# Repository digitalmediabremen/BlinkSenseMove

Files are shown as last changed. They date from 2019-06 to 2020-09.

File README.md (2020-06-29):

# Blink Sense Move.

A general purpose PCB/Toolkit for easy usage of sensors and actuators

# Hardware

1. maximum PCB dimensions: 100×100mm ( = 1,76/10pcs @[jlcpcb](http://jlcpcb.com) )
2. uses teensy 3.2 as mcu
3. features
  - 2 mosfets
  - h-bridge
  - amplfiers for external sensors
  - display (only dotmatrix for now, v2 will also offer pins for oled)
  - stepperdriver
  - clean audio output with lpf
  - potentiometers
  - buttons
  - patchable io
  
4. version 2 will feature
  - midi
  - choice of display
  - possibly cleaner powersolution

-----
## Pre v01

## MCU-Ideas

( supported by Arduino IDE )

1. ATmega328p (AVR, 20 MHz, 8-bit, @as_used_in(Arduino UNO)), pP 1.60€, [Datasheet](http://www.microchip.com/mymicrochip/filehandler.aspx?ddocname=en589666)
2. NXP MK20DX256 (ARM Cortex-M4, 96 MHz, 32-bit, @as_used_in(Teensy 3.2) ), pP 9.00€, [Datasheet](https://www.pjrc.com/teensy/K20P64M72SF1.pdf)
3. STM32F446RE (ARM Cortex-M4, 180 MHz, 32-bit, @as_used_in(Nucleo F446RE + Arduino for STM32)), pP 9.00€, [Datasheet](http://www.st.com/content/ccc/resource/technical/document/datasheet/65/cb/75/50/53/d6/48/24/DM00141306.pdf/files/DM00141306.pdf/jcr:content/translations/en.DM0014130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)

### Boards

1) Teensy LC (approx 13 Euro) | Teensy 3.2 (Pro: Fast, Audiocapabilitys. Contra: Not super cheap)
2) Arduino Nano (Pro: Compatibilty, cheap. Contra: CH340-Driver issue with cheap Variations)

## Ideas for Features

1) Felix´ Audio Output board
2) 1 or 2 Mosfets with Diodes
3) 12v Input with good Quality Voltage converter
4) Stepper Motor Driver
5) H-Bridge
6) 7-Segment-Display
7) Add-On-Interface for stuff like Encoders or Analogsticks and similiar stuff.
8) motor board *only* ( H-bridge+mosfet, stepper-driver, PWM for high-current/loads )
9) Making the wiring Modular
10) Mic- and Piezoamp, maybe also a switchable direct out to Felix Audio out.
11) frequency devider / counter ic
12) Making it modular (plugging and using boards together, with one microcontroller)
13) encoder
14) 2 potis

## Bill of materials
- 3.5 mm jack
- AKL
- 595 (SMD?)
- IRF530 (SMD)
- 7seg/4Digit
- spannungsregler MC7805CD2TG (SMD) (1A 5V für teensy und externe komponenten)

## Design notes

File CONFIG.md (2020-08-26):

# BSM Configuration

## Teensy
## Jumpers

Jumpers on BSM are used to create or break connections on the board. This allows to customize it to your needs.

Three kinds of Jumpers are used on the board
1. Black jumpers
    Black jumpers are freely configuable. They just break or create connections, mainly around the teensy. 
2. Red jumpers
    Red jumpers are danger jumpers! Take care when using these! These are used for configuring the powersupply and selecting between external power or usb power. It is possible to damage something with these, so think before jumping!
3. Blue jumpers
    blue jumpers are selection jumpers. They are used in certain places to select configuration, for example to configure the stepper driver or h-bridge.

## Power

## Stepper druver

## H-bridge

## Display

## Mosfet

## Betteraudioout

## Sensorport

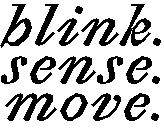
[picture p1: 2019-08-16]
hardware/pcb/DM_PCB_GRAPHICS/DM_PCB_EASTEREGG.BMP

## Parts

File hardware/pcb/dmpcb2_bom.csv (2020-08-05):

Part | Value | Device | Package | Description
3.3V |  | MA03-2 | MA03-2 | PIN HEADER
5V |  | MA03-2 | MA03-2 | PIN HEADER
14/DAC |  | JP1E | JP1 | JUMPER
C1 | 0.33uF | CPOL-EUSANYO_A' | SANYO-OSCON_A' | POLARIZED CAPACITOR, European symbol
C2 | 0.1uF | CPOL-EUSANYO_A' | SANYO-OSCON_A' | POLARIZED CAPACITOR, European symbol
C3 | 1000uf | CPOL-EUE3.5-8 | E3,5-8 | POLARIZED CAPACITOR, European symbol
C4 | 100nf | C-EUC0805 | C0805 | CAPACITOR, European symbol
C5 | 100nf | C-EUC0805 | C0805 | CAPACITOR, European symbol
C6 | 100nf | C-EUC0805 | C0805 | CAPACITOR, European symbol
C7 | 100uf | CPOL-EUE5-5 | E5-5 | POLARIZED CAPACITOR, European symbol
C8 | 100uf | CPOL-EUE5-5 | E5-5 | POLARIZED CAPACITOR, European symbol
C9 | 100uf | CPOL-EUE5-5 | E5-5 | POLARIZED CAPACITOR, European symbol
C10 | 100nf | C-EUC0805 | C0805 | CAPACITOR, European symbol
C11 | 10uf | C-EUC0805 | C0805 | CAPACITOR, European symbol
D3 | 1N4148DO35-7 | 1N4148DO35-7 | DO35-7 | DIODE
D4 | 1N4148DO35-7 | 1N4148DO35-7 | DO35-7 | DIODE
DRV8825 | POLOLU-DRV8825 | POLOLU-DRV8825 | POLOLU-DRV8825
EXT_5V |  | JP1E | JP1 | JUMPER
EXT_5V1 |  | JP1E | JP1 | JUMPER
GND |  | MA03-2 | MA03-2 | PIN HEADER
HOLA |  | JP1E | JP1 | JUMPER
HOLB |  | JP1E | JP1 | JUMPER
HOLC |  | JP1E | JP1 | JUMPER
HOLD |  | JP1E | JP1 | JUMPER
IC1 | 7805DT | 7805DT | TO252 | Positive VOLTAGE REGULATOR
IC2 | L293D | L293D | DIL16 | PUSH-PULL 4 CHANNEL DRIVER
IC4 | LM358D | LM358D | SO08 | OP AMP also LM158; LM258; LM2904
IC5 | LM358D | LM358D | SO08 | OP AMP also LM158; LM258; LM2904
J1 |  | CONN_11 | 1X11 | Multi connection point. Often used as Generic Header-pin footprint for 0.1 inch spaced/style header connections
J2 |  | CONN_14 | 1X14 | Multi connection point. Often used as Generic Header-pin footprint for 0.1 inch spaced/style header connections
J4 |  | CONN_03LOCK_LONGPADS | 1X03_LOCK_LONGPADS | Multi connection point. Often used as Generic Header-pin footprint for 0.1 inch spaced/style header connections
J7 | SJ-3523-SMT-TR | SJ-3523-SMT-TR | CUI_SJ-3523-SMT-TR | Audio Jack Connector 3.5 mm Low Profile Surface Mount Stereo Jack, 3 Pin Right-Angle
J8 |  | CONN_04 | 1X04 | Multi connection point. Often used as Generic Header-pin footprint for 0.1 inch spaced/style header connections
J9 |  | CONN_14 | 1X14 | Multi connection point. Often used as Generic Header-pin footprint for 0.1 inch spaced/style header connections
JP1 |  | JP2E | JP2 | JUMPER
JP3 |  | JP3Q | JP3Q | JUMPER
JP4 |  | JP2E | JP2 | JUMPER
JP5 |  | JP2E | JP2 | JUMPER
LED_01 |  | LEDSML0805 | SML0805 | LED
LED_02 |  | LEDSML0805 | SML0805 | LED
LED_03 |  | LEDSML0805 | SML0805 | LED
Q1 | IRF530 | IRF530 | TO220BV | HEXFET Power MOSFET
Q2 | IRF530 | IRF530 | TO220BV | HEXFET Power MOSFET
R1 | 100k | R-US_R0805 | R0805 | RESISTOR, American symbol
R2 | 1k | R-US_R0805 | R0805 | RESISTOR, American symbol
R3 | 100k | R-EU_R0805 | R0805 | RESISTOR, European symbol
R4 | 220R | R-EU_R0805 | R0805 | RESISTOR, European symbol
R5 | 100k | R-US_R0805 | R0805 | RESISTOR, American symbol
R6 | 1k | R-US_R0805 | R0805 | RESISTOR, American symbol
R7 | b10k | POTENTIOMETER_PT-10 | PT-10 | Potentiometer
R8 | b10k | POTENTIOMETER_PT-10 | PT-10 | Potentiometer
R9 | 1M | R-EU_M0805 | M0805 | RESISTOR, European symbol
R10 | 10M | R-EU_M0805 | M0805 | RESISTOR, European symbol
R11 | 10K | R-EU_M0805 | M0805 | RESISTOR, European symbol
R12 | 10k | R-EU_M0805 | M0805 | RESISTOR, European symbol
R13 | 10k | R-EU_M0805 | M0805 | RESISTOR, European symbol
R14 | 220R | R-EU_R0805 | R0805 | RESISTOR, European symbol
R15 | b100k | TRIM_EU-RJ9W | RJ9W | POTENTIOMETER
R16 | 10K | R-EU_M0805 | M0805 | RESISTOR, European symbol
R17 | b10k | TRIM_EU-RJ9W | RJ9W | POTENTIOMETER
R18 | 270R | R-EU_M0805 | M0805 | RESISTOR, European symbol
R19 | b10k | TRIM_EU-RJ9W | RJ9W | POTENTIOMETER
R20 | 220R | R-EU_R0805 | R0805 | RESISTOR, European symbol
S1 |  | 10-XX | B3F-10XX | OMRON SWITCH
S2 |  | 10-XX | B3F-10XX | OMRON SWITCH
SOCKET_IN |  | MA05-1 | MA05-1 | PIN HEADER
SOCKET_IN1 |  | MA05-1 | MA05-1 | PIN HEADER
STP_CONF |  | JP2E | JP2 | JUMPER
SV1 |  | MA07-1 | MA07-1 | PIN HEADER
SV2 |  | CONN_12 | 1X12 | Multi connection point. Often used as Generic Header-pin footprint for 0.1 inch spaced/style header connections
TEENSY3.2 | TEENSY_3.1-3.2_ALL_PINS&PADS | TEENSY_3.1-3.2_ALL_PINS&PADS | TEENSY_3.0-3.2_ALL_PINS_&_PADS | Footprint for Teensy 3.1 or 3.2 board using all pads and all through-holes. Pads need a 2x7 0.1 SMD header."
X1 |  | W237-102 | W237-102 | WAGO SCREW CLAMP
X2 |  | W237-4 | W237-4 | WAGO SCREW CLAMP
X3 |  | W237-102 | W237-102 | WAGO SCREW CLAMP
X4 |  | W237-102 | W237-102 | WAGO SCREW CLAMP
X5 |  | W237-102 | W237-102 | WAGO SCREW CLAMP
X6 |  | W237-102 | W237-102 | WAGO SCREW CLAMP
X7 |  | W237-102 | W237-102 | WAGO SCREW CLAMP
X8 |  | W237-102 | W237-102 | WAGO SCREW CLAMP

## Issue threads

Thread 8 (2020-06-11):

Labeling for J8 is missing

TimoJohannes, 2020-06-11:
add labeling to enable easier patching of second opamp circuit.

TimoJohannes, 2020-08-07:
added for v02

Closed 2020-08-07.

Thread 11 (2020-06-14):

Overthink display

TimoJohannes, 2020-06-14:
Dotmatrices are cool and all, but do they make sense didactically? maybe an oled display would make more sense? They are priced similarly as the dmds and offer greater and more vivid outputs.
Only problem is the noise they introduce into the powercircuit, maybe some good filtering could be used. Thanks felix for the input
Thoughts?

TimoJohannes, 2020-06-25:
Add Pins for 4 pin oled beneath the dotmatrix. User can chose what kind of display they want to use

TimoJohannes, 2020-07-14:
Done, added pins for 7pin oled + some filtering

Closed 2020-07-14.

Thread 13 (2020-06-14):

Add LEDs

TimoJohannes, 2020-06-14:
Adding one or two user controllable leds on board would offer some output possibilities.

TimoJohannes, 2020-08-07:
Added for v02

Closed 2020-08-07.

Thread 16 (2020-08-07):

Replace Footprint of headers

TimoJohannes, 2020-08-07:
Replace footprints of headers with the staggered ones from sparkfun, makes soldering them easier.

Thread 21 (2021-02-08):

Opamp gets fed with 5v, should only be powered by 3.3v. might damage teensy!

TimoJohannes, 2021-02-08:

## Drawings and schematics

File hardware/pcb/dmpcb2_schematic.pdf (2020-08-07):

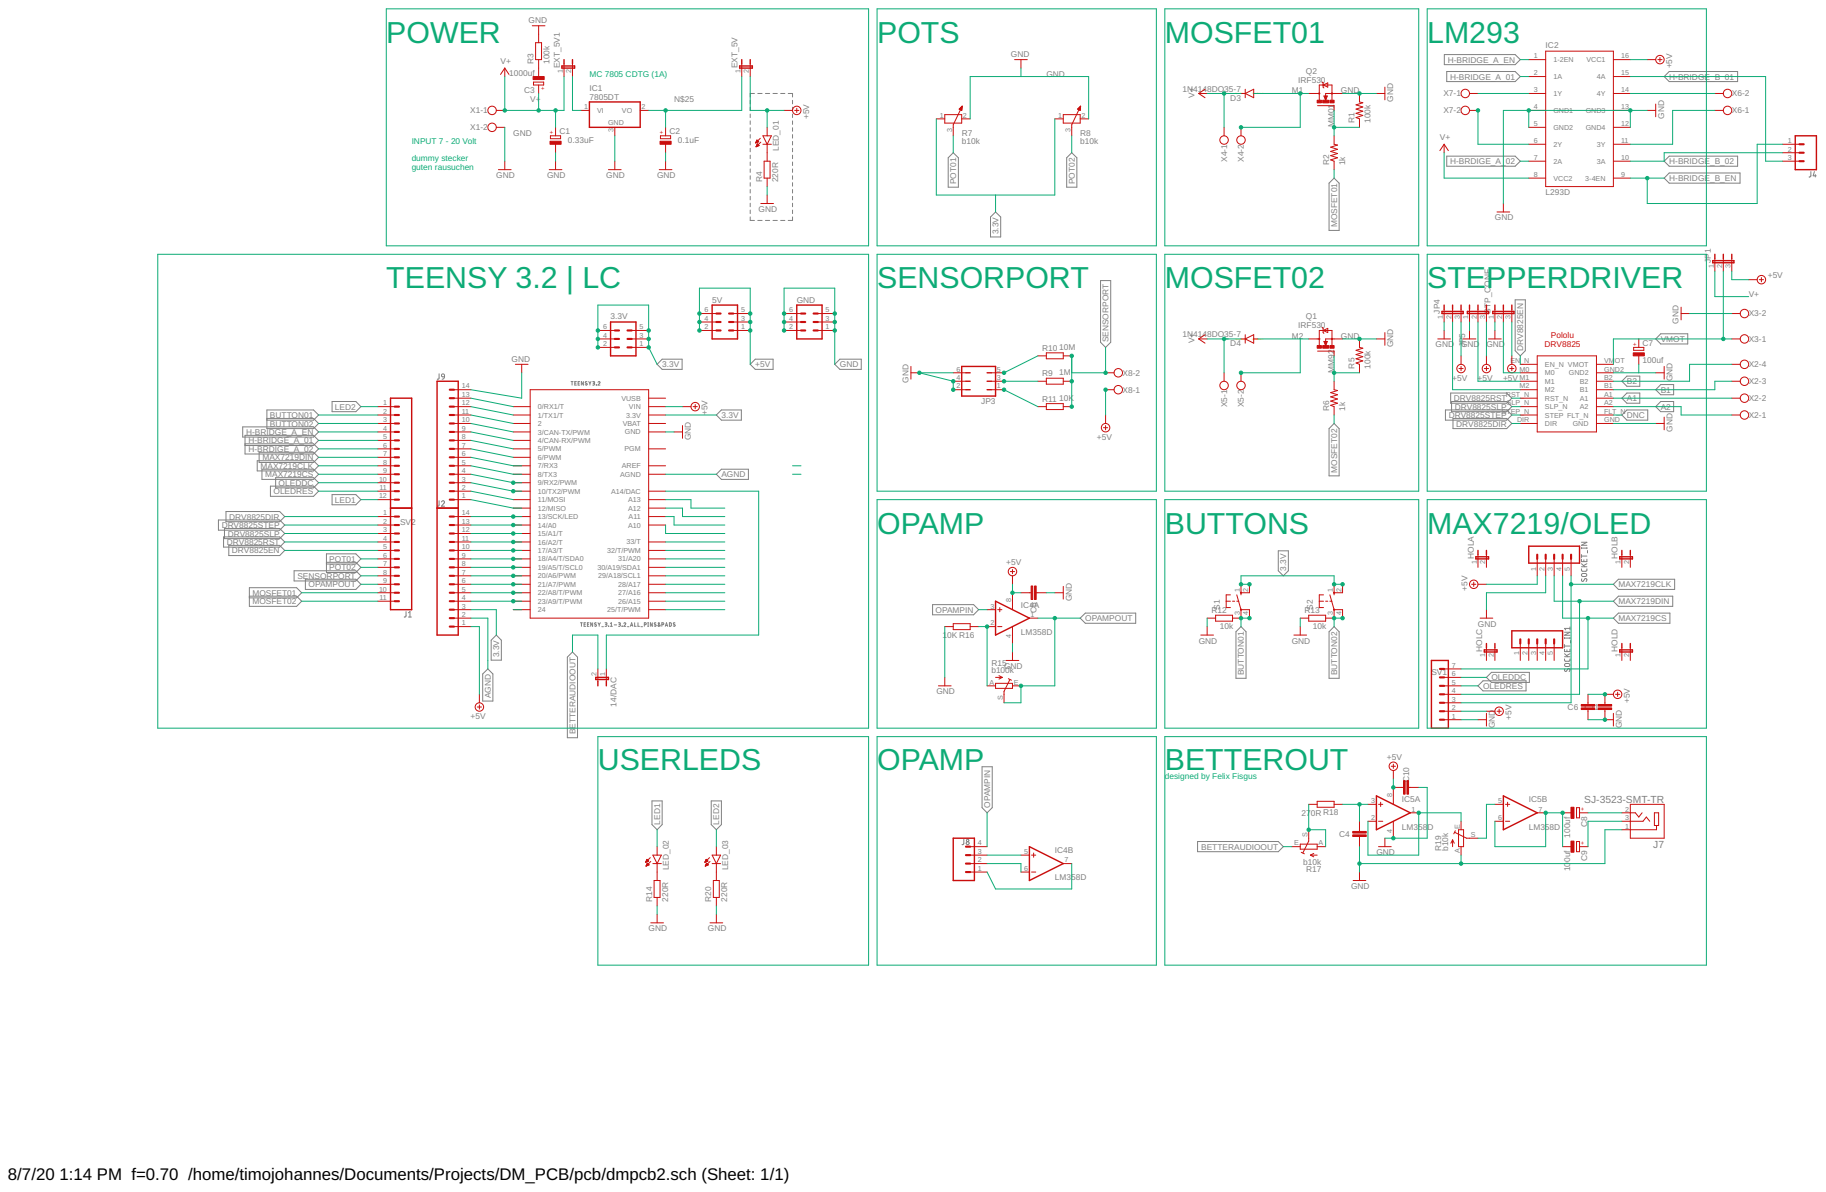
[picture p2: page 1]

6 OLEDDC

8/7/20 1:14 PM f=0.70 /home/timojohannes/Documents/Projects/DM_PCB/pcb/dmpcb2.sch (Sheet: 1/1)

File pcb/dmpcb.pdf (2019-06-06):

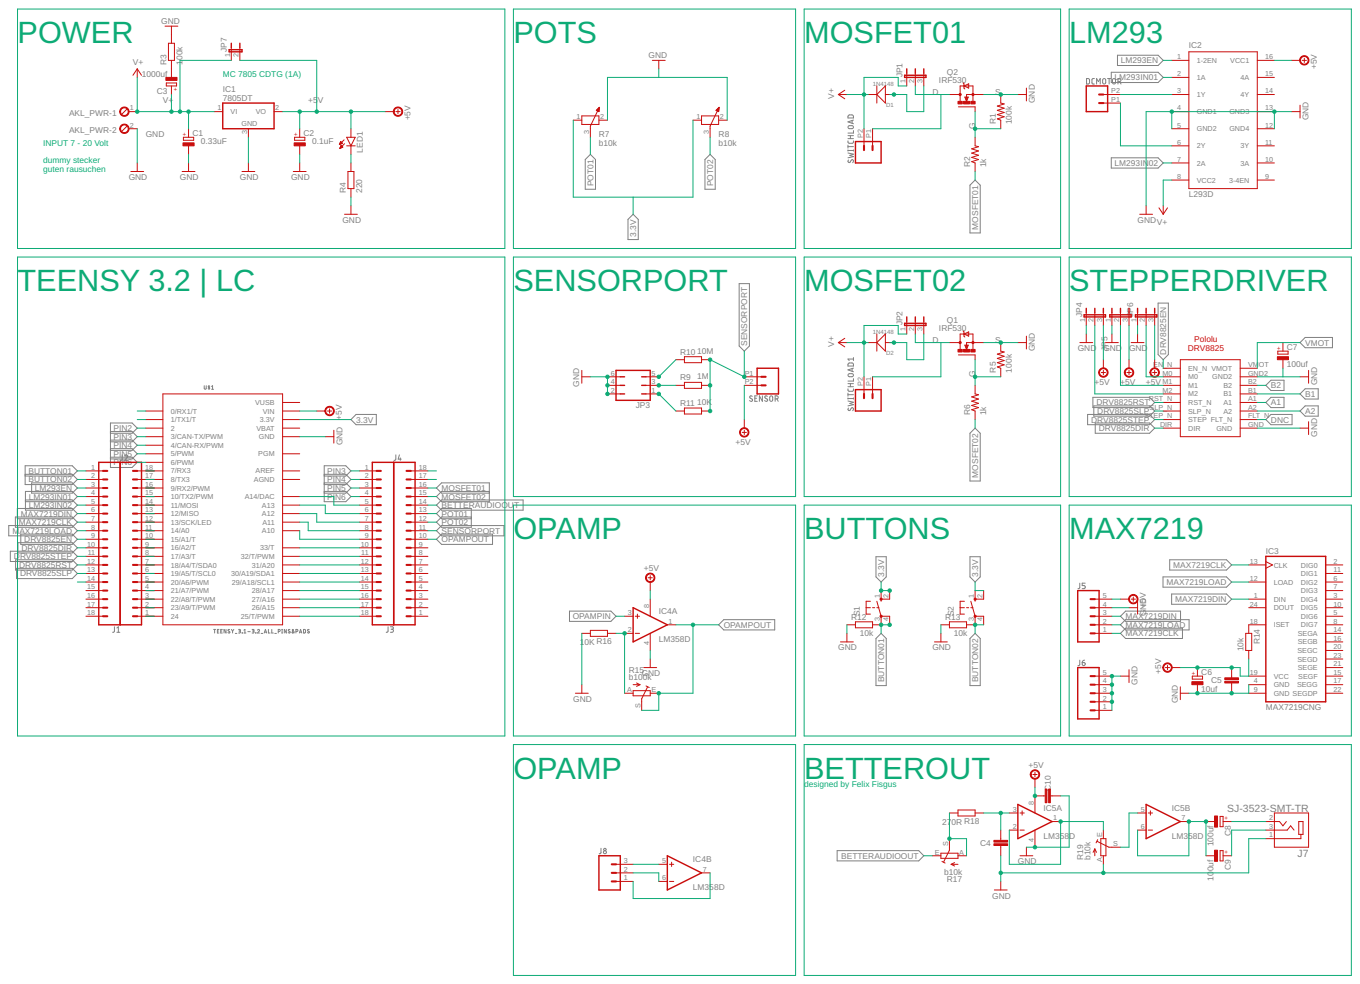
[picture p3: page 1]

12 | | 7
11 | | 8
10 | | 9
9 | 10
8 | 11

5 | 14
4 | 15
3 | 16

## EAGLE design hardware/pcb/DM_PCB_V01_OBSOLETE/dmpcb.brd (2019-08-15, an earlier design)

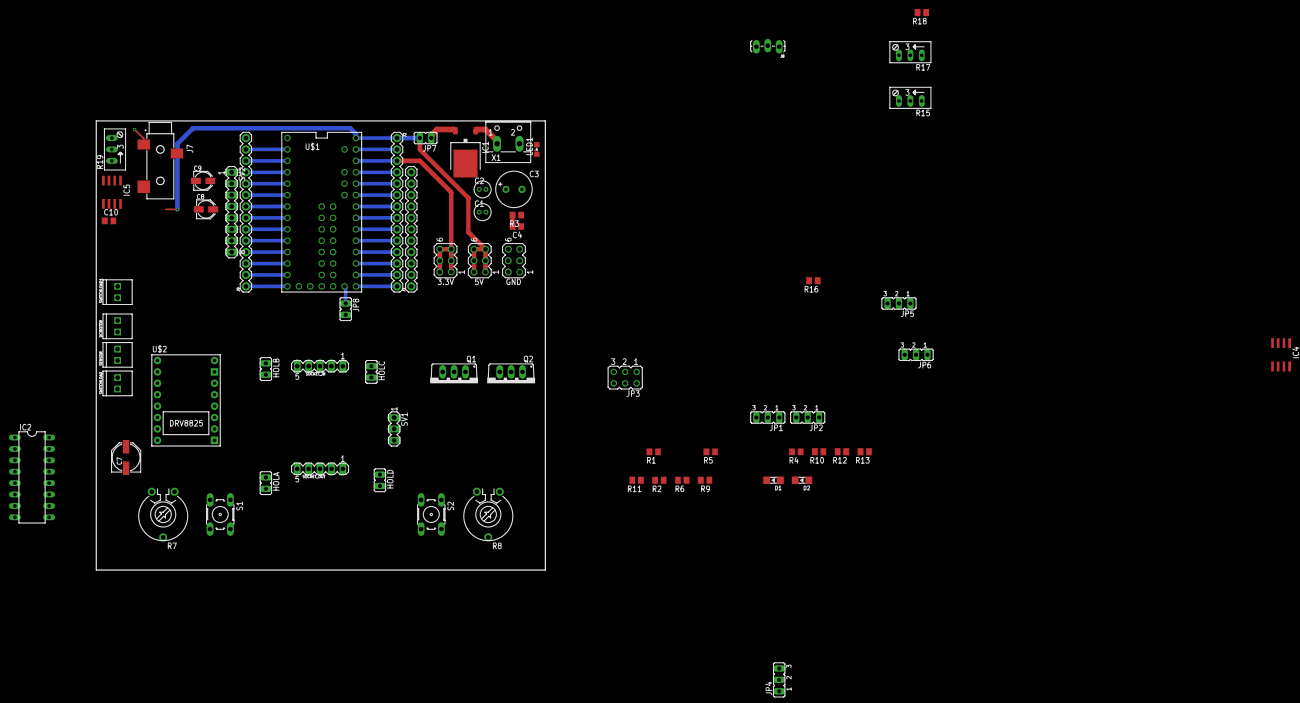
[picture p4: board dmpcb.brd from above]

Board: 2 copper layers, 100.0 x 100.0 mm, 68 parts (0 on the bottom side), 80 nets.

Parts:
3.3V, 5V: MA03-2
C1: 0.33uF; SANYO-OSCON_A'
C2: 0.1uF; SANYO-OSCON_A'
C3: 1000uf; E3,5-8
C4, C10: 100nf; C0805
C7: 100uf; PANASONIC_D
C8, C9: 100uf; PANASONIC_B
D1, D2: 1N4148; LL-34
DCMOTOR: 1X02_2.54_SCREWTERM
GND: MA03-2
HOLA: JP1
HOLB: JP1
HOLC: JP1
HOLD: JP1
IC1: 7805DT; TO252
IC2: L293D; DIL16
IC4, IC5: LM358D; SO08
J1: 1X11
J2, J9: 1X14
J7: SJ-3523-SMT-TR; CUI_SJ-3523-SMT-TR
J8: 1X03_LOCK_LONGPADS
JP1, JP2, JP4, JP5, JP6: JP2
JP3: JP3Q
JP7, JP8: JP1
LED1: SML0805
Q1, Q2: IRF530; TO220BV
R1, R3, R5: 100k; R0805
R2, R6: 1k; R0805
R4: 220; R0805
R7, R8: b10k; PT-10
R9: 1M; M0805
R10: 10M; M0805
R11, R16: 10K; M0805
R12, R13: 10k; M0805
R15: b100k; RJ9W
R17, R19: b10k; RJ9W
R18: 270R; M0805
S1, S2: B3F-10XX
SENSOR: 1X02_2.54_SCREWTERM
SOCKET_IN: MA05-1
SOCKET_OUT: MA05-1
SV1: MA03-1
SV2: MA08-1
SWITCHLOAD, SWITCHLOAD1: 1X02_2.54_SCREWTERM
U$1: TEENSY_3.1-3.2_ALL_PINS&PADS; TEENSY_3.0-3.2_ALL_PINS_&_PADS
U$2: POLOLU-DRV8825
X1: W237-102

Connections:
3.3V: 3.3V.1, 3.3V.2, 3.3V.3, 3.3V.4, 3.3V.5, 3.3V.6, J2.3, R7.1, R8.1, U$1.3.3V, U$1.3.3V1, U$1.3.3V2
+5V: 5V.1, 5V.2, 5V.3, 5V.4, 5V.5, 5V.6, C10.2, IC2.16, IC4.8, IC5.8, J2.1, JP4.3, JP5.3, JP6.3, JP7.2, SENSOR.P2, SOCKET_IN.1, U$1.VIN
AGND: J2.2, U$1.AGND
BETTERAUDIOOUT: JP8.2, R17.E
BUTTON01: R12.2, S1.3, S1.4, SV2.1
BUTTON02: R13.2, S2.3, S2.4, SV2.2
D: JP1.2, JP2.2, Q1.D, Q2.D, SWITCHLOAD.P1, SWITCHLOAD1.P1
DRV8825DIR: J1.2, U$2.DIR
DRV8825EN: J1.1, U$2.EN_N
DRV8825RST: J1.4, U$2.RST_N
DRV8825SLP: J1.5, U$2.SLP_N
DRV8825STEP: J1.3, U$2.STEP_N
G: Q1.G, Q2.G, R1.1, R2.2, R5.1, R6.2
GND: C1.-, C2.-, C4.2, C7.-, C10.1, GND.1, GND.2, GND.3, GND.4, GND.5, GND.6, IC1.3, IC2.4, IC2.5, IC2.12, IC2.13, IC4.4, IC5.4, J7.1, J9.14, JP3.2, JP3.4, JP3.6, JP4.1, JP5.1, JP6.1, R3.2, R4.1, R7.2, R8.2, R12.1, R13.1, R16.2, R19.A, SOCKET_IN.2, U$1.GND, U$1.GND1, U$1.GND2, U$2.GND, U$2.GND2, X1.2
LM293EN: IC2.1, SV2.3
LM293IN01: IC2.2, SV2.4
LM293IN02: IC2.7, SV2.5
MAX7219CLK: SOCKET_IN.5, SV1.1, SV2.7
MAX7219CS: SOCKET_IN.4, SV1.2, SV2.8
MAX7219DIN: SOCKET_IN.3, SV1.3, SV2.6
MOSFET01: J1.10, R2.1
MOSFET02: J1.11, R6.1
unnamed: DCMOTOR.P2, IC2.3
unnamed: DCMOTOR.P1, IC2.6
unnamed: C3.-, R3.1
unnamed: LED1.C, R4.2
unnamed: D2.A, JP2.3
unnamed: D1.A, JP1.3
unnamed: JP3.5, R10.1
unnamed: JP3.3, R9.1
unnamed: JP3.1, R11.1
unnamed: S1.1, S1.2
unnamed: IC4.5, J8.3
unnamed: S2.1, S2.2
unnamed: J2.4, U$1.23/A9
unnamed: C2.+, IC1.2, JP7.1, LED1.A
unnamed: J2.5, U$1.22/A8
unnamed: J2.6, U$1.21/A7
unnamed: J2.7, U$1.20/A6
unnamed: J2.8, U$1.19/A5
unnamed: J2.9, U$1.18/A4
unnamed: J2.10, U$1.17/A3
unnamed: J2.11, U$1.16/A2
unnamed: J2.12, U$1.15/A1
unnamed: J2.13, U$1.14/A0
unnamed: J2.14, U$1.13
unnamed: J9.1, U$1.12
unnamed: J9.2, U$1.11
unnamed: J9.3, U$1.10
unnamed: J9.4, U$1.9
unnamed: J9.5, U$1.8
unnamed: J9.6, U$1.7
unnamed: JP8.1, U$1.RESET/DAC
unnamed: JP4.2, U$2.M2
unnamed: JP5.2, U$2.M1
unnamed: JP6.2, U$2.M0
unnamed: J9.12, U$1.1
unnamed: J9.13, U$1.0
unnamed: IC4.2, R15.A, R16.1
unnamed: C8.+, J7.2
unnamed: R17.A, R17.S, R18.2
unnamed: C4.1, IC5.3, R18.1
unnamed: IC5.1, IC5.2, R19.E
unnamed: IC4.6, J8.2
unnamed: IC5.5, R19.S
unnamed: C8.-, C9.-, IC5.6, IC5.7
unnamed: C9.+, J7.3
unnamed: IC4.7, J8.1
OPAMPOUT: IC4.1, J1.9, R15.E, R15.S
PIN2: J9.11, U$1.2
PIN3: J9.10, U$1.3
PIN4: J9.9, U$1.4
PIN5: J9.8, U$1.5
PIN6: J9.7, U$1.6
POT01: J1.6, R7.3
POT02: J1.7, R8.3
S: Q1.S, Q2.S, R1.2, R5.2
SENSORPORT: J1.8, R9.2, R10.2, R11.2, SENSOR.P1
V+: C1.+, C3.+, D1.C, D2.C, IC1.1, IC2.8, JP1.1, JP2.1, SWITCHLOAD.P2, SWITCHLOAD1.P2, X1.1
VMOT: C7.+, U$2.VMOT

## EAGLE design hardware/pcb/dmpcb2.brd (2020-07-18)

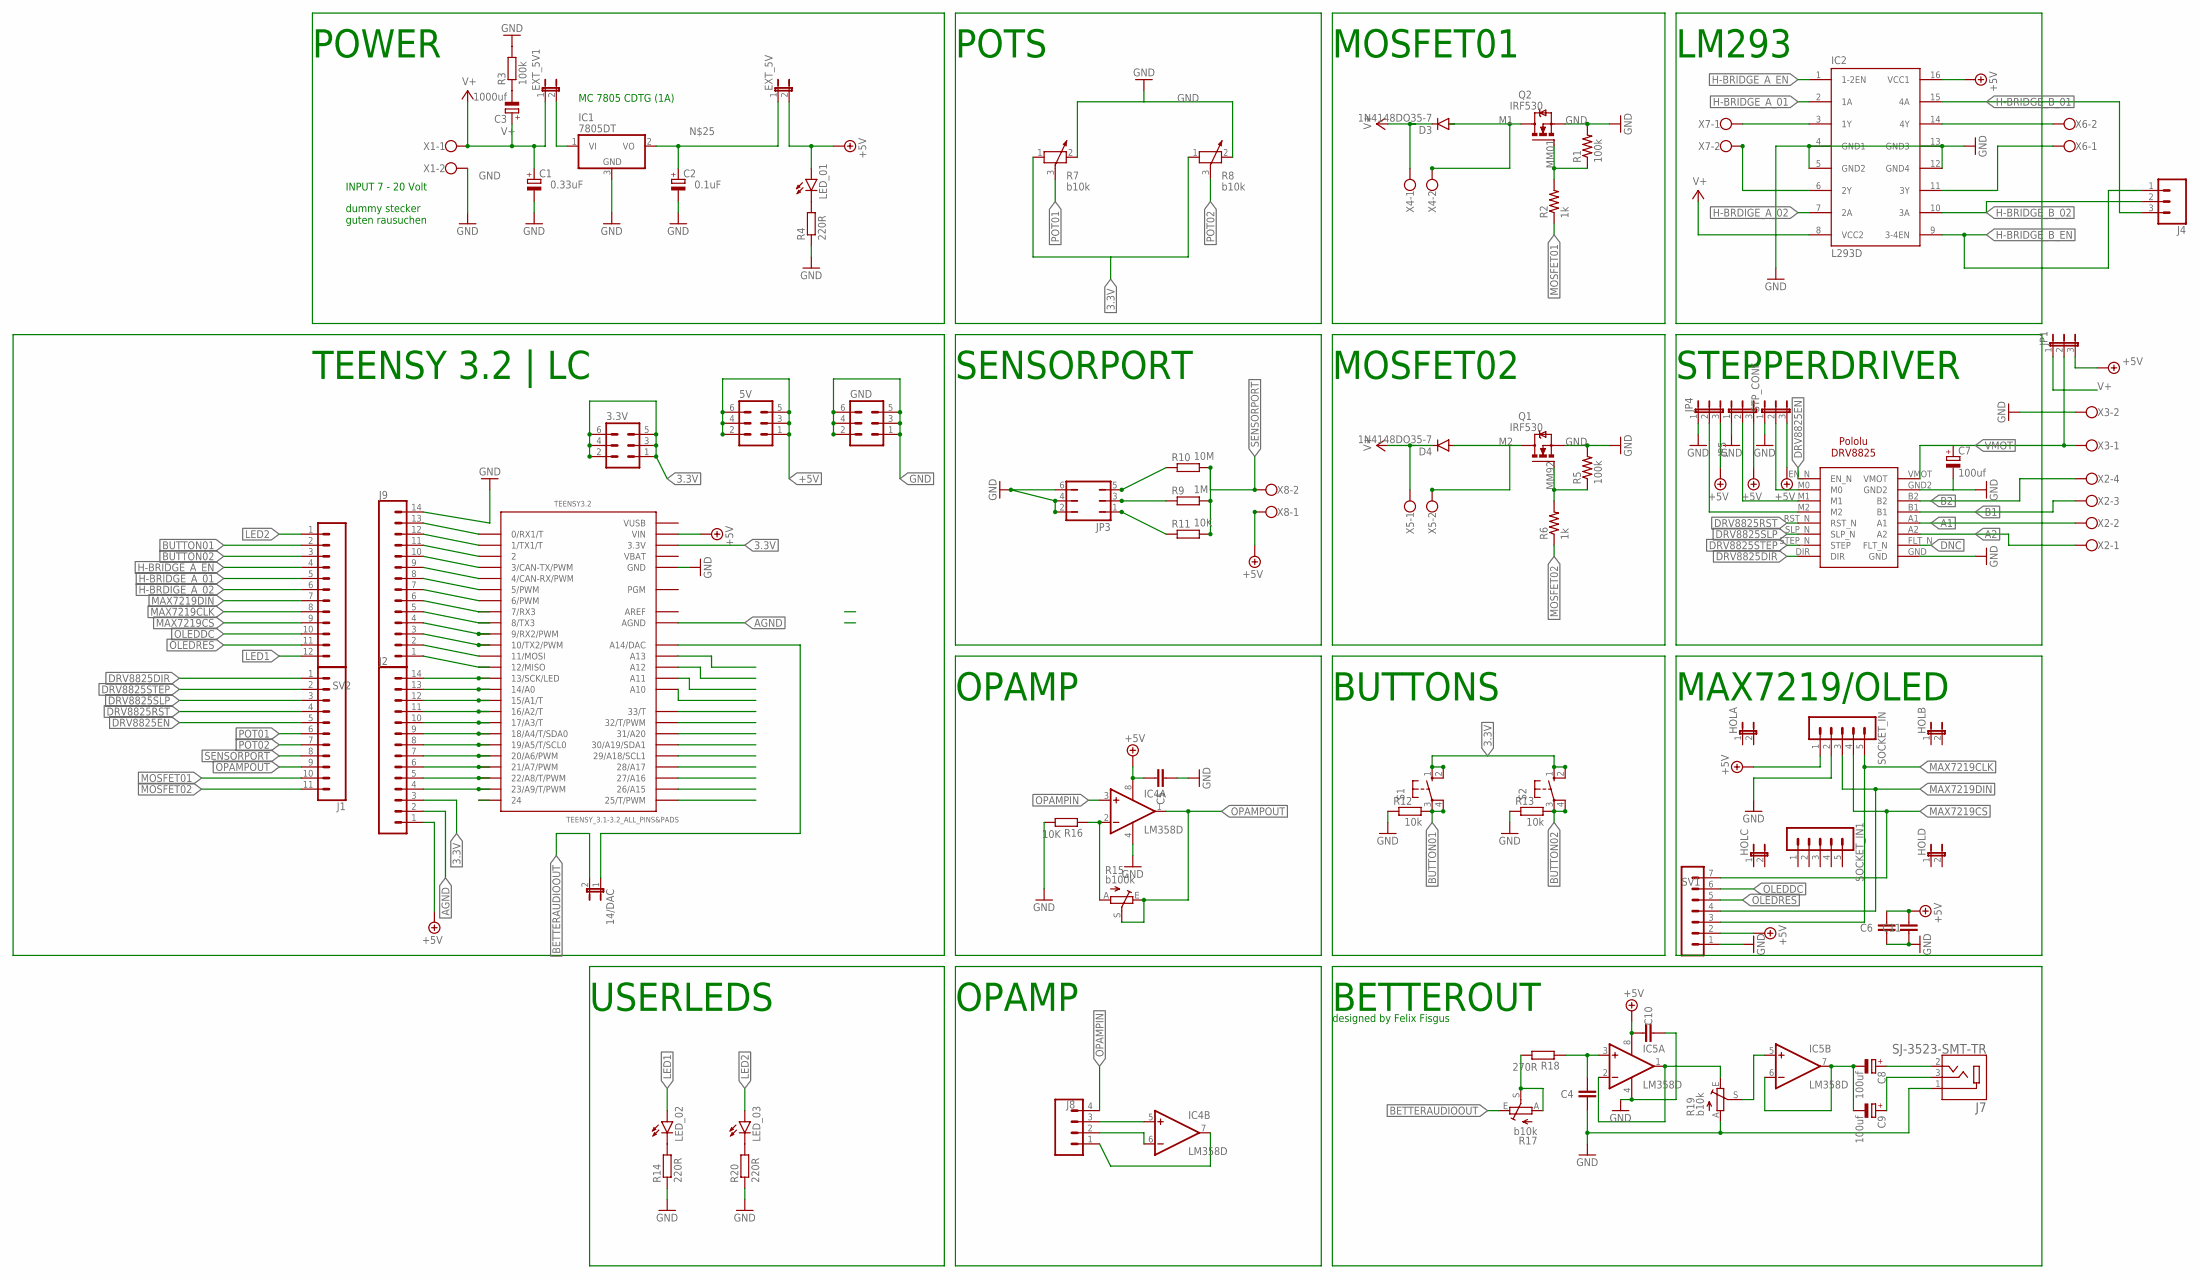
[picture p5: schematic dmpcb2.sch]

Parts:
3.3V, 5V: MA03-2
14/DAC: JP1E; JP1
C1: 0.33uF; SANYO-OSCON_A'
C2: 0.1uF; SANYO-OSCON_A'
C3: 1000uf; E3,5-8
C4, C5, C6, C10: 100nf; C0805
C7, C8, C9: 100uf; E5-5
C11: 10uf; C0805
D3, D4: 1N4148DO35-7; DO35-7
DRV8825: POLOLU-DRV8825
EXT_5V, EXT_5V1: JP1E; JP1
GND: MA03-2
HOLA: JP1E; JP1
HOLB: JP1E; JP1
HOLC: JP1E; JP1
HOLD: JP1E; JP1
IC1: 7805DT; TO252
IC2: L293D; DIL16
IC4, IC5: LM358D; SO08
J1: CONN_11; 1X11
J2, J9: CONN_14; 1X14
J4: CONN_03LOCK_LONGPADS; 1X03_LOCK_LONGPADS
J7: SJ-3523-SMT-TR; CUI_SJ-3523-SMT-TR
J8: CONN_04; 1X04
JP1, JP4, JP5: JP2E; JP2
JP3: JP3Q
LED_01, LED_02, LED_03: LEDSML0805; SML0805
Q1, Q2: IRF530; TO220BV
R1, R3, R5: 100k; R0805
R2, R6: 1k; R0805
R4, R14, R20: 220R; R0805
R7, R8: b10k; PT-10
R9: 1M; M0805
R10: 10M; M0805
R11, R16: 10K; M0805
R12, R13: 10k; M0805
R15: b100k; RJ9W
R17, R19: b10k; RJ9W
R18: 270R; M0805
S1, S2: 10-XX; B3F-10XX
SOCKET_IN, SOCKET_IN1: MA05-1
STP_CONF: JP2E; JP2
SV1: MA07-1
SV2: CONN_12; 1X12
TEENSY3.2: TEENSY_3.1-3.2_ALL_PINS&PADS; TEENSY_3.0-3.2_ALL_PINS_&_PADS
X1, X3, X4, X5, X6, X7, X8: W237-102
X2: W237-4

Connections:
3.3V: 3.3V.1, 3.3V.2, 3.3V.3, 3.3V.4, 3.3V.5, 3.3V.6, J2.3, R7.1, R8.1, S1.1 (S), S1.2 (S1), S2.1 (S), S2.2 (S1), TEENSY3.2.3.3V, TEENSY3.2.3.3V1 (3.3V), TEENSY3.2.3.3V2 (3.3V)
+5V: 5V.1, 5V.2, 5V.3, 5V.4, 5V.5, 5V.6, C5.1, C6.1, C10.2, C11.1, EXT_5V.2, IC2.16 (VCC1), IC4.8 (V+), IC5.8 (V+), J2.1, JP1.3, JP4.3, JP5.3, LED_01.A, SOCKET_IN.1, STP_CONF.3, SV1.2, TEENSY3.2.VIN, X8.1
A1: DRV8825.A1, X2.2
A2: DRV8825.A2, X2.1
AGND: J2.2, TEENSY3.2.AGND
AREF: TEENSY3.2.AREF
B1: DRV8825.B1, X2.3
B2: DRV8825.B2, X2.4
BETTERAUDIOOUT: 14/DAC.2, R17.E
BUTTON01: R12.2, S1.3, S1.4 (P1), SV2.2
BUTTON02: R13.2, S2.3, S2.4 (P1), SV2.3
DNC: DRV8825.FLT_N
DRV8825DIR: DRV8825.DIR, J1.1
DRV8825EN: DRV8825.EN_N, J1.5
DRV8825RST: DRV8825.RST_N, J1.4
DRV8825SLP: DRV8825.SLP_N, J1.3
DRV8825STEP: DRV8825.STEP_N (STEP), J1.2
GND: C1.-, C2.-, C4.2, C5.2, C6.2, C7.-, C10.1, C11.2, DRV8825.GND, DRV8825.GND2, GND.1, GND.2, GND.3, GND.4, GND.5, GND.6, IC1.3 (GND), IC2.4 (GND1), IC2.5 (GND2), IC2.12 (GND4), IC2.13 (GND3), IC4.4 (V-), IC5.4 (V-), J7.1, J9.14, JP3.2, JP3.4, JP3.6, JP4.1, JP5.1, Q1.S, Q2.S, R1.2, R3.2, R4.1, R5.2, R7.2, R8.2, R12.1, R13.1, R14.1, R16.2, R19.A, R20.1, SOCKET_IN.2, STP_CONF.1, SV1.1, TEENSY3.2.GND, TEENSY3.2.GND1 (GND), TEENSY3.2.GND2 (GND), X1.2, X3.2
H-BRDIGE_A_02: IC2.7 (2A), SV2.6
H-BRIDGE_A_01: IC2.2 (1A), SV2.5
H-BRIDGE_A_EN: IC2.1 (1-2EN), SV2.4
H-BRIDGE_B_01: IC2.15 (4A), J4.3
H-BRIDGE_B_02: IC2.10 (3A), J4.2
H-BRIDGE_B_EN: IC2.9 (3-4EN), J4.1
LED1: LED_02.A, SV2.12
LED2: LED_03.A, SV2.1
M1: D3.A, Q2.D, X4.2
M2: D4.A, Q1.D, X5.2
MAX7219CLK: SOCKET_IN.5, SV1.3, SV2.8
MAX7219CS: SOCKET_IN.4, SV1.7, SV2.9
MAX7219DIN: SOCKET_IN.3, SV1.4, SV2.7
MM01: Q2.G, R1.1, R2.2
MM92: Q1.G, R5.1, R6.2
MOSFET01: J1.10, R2.1
MOSFET02: J1.11, R6.1
unnamed: IC2.3 (1Y), X7.1
unnamed: IC2.6 (2Y), X7.2
unnamed: C3.-, R3.1
unnamed: LED_01.C, R4.2
unnamed: IC2.14 (4Y), X6.2
unnamed: IC2.11 (3Y), X6.1
unnamed: JP3.5, R10.1
unnamed: JP3.3, R9.1
unnamed: JP3.1, R11.1
unnamed: EXT_5V1.2, IC1.1 (VI)
unnamed: IC4.5 (+IN), J8.3
unnamed: J2.4, TEENSY3.2.23/A9 (23/A9/T/PWM)
unnamed: C2.+, EXT_5V.1, IC1.2 (VO)
unnamed: J2.5, TEENSY3.2.22/A8 (22/A8/T/PWM)
unnamed: J2.6, TEENSY3.2.21/A7 (21/A7/PWM)
unnamed: J2.7, TEENSY3.2.20/A6 (20/A6/PWM)
unnamed: J2.8, TEENSY3.2.19/A5 (19/A5/T/SCL0)
unnamed: J2.9, TEENSY3.2.18/A4 (18/A4/T/SDA0)
unnamed: J2.10, TEENSY3.2.17/A3 (17/A3/T)
unnamed: J2.11, TEENSY3.2.16/A2 (16/A2/T)
unnamed: J2.12, TEENSY3.2.15/A1 (15/A1/T)
unnamed: J2.13, TEENSY3.2.14/A0
unnamed: J2.14, TEENSY3.2.13 (13/SCK/LED)
unnamed: J9.1, TEENSY3.2.12 (12/MISO)
unnamed: J9.2, TEENSY3.2.11 (11/MOSI)
unnamed: J9.3, TEENSY3.2.10 (10/TX2/PWM)
unnamed: J9.4, TEENSY3.2.9 (9/RX2/PWM)
unnamed: J9.5, TEENSY3.2.8 (8/TX3)
unnamed: J9.6, TEENSY3.2.7 (7/RX3)
unnamed: 14/DAC.1, TEENSY3.2.RESET/DAC (A14/DAC)
unnamed: DRV8825.M2, JP4.2
unnamed: DRV8825.M1, JP5.2
unnamed: DRV8825.M0, STP_CONF.2
unnamed: J9.12, TEENSY3.2.1 (1/TX1/T)
unnamed: J9.13, TEENSY3.2.0 (0/RX1/T)
unnamed: IC4.2 (-IN), R15.A, R16.1
unnamed: LED_02.C, R14.2
unnamed: C8.+, J7.2
unnamed: R17.A, R17.S, R18.2
unnamed: C4.1, IC5.3 (+IN), R18.1
unnamed: IC5.1 (OUT), IC5.2 (-IN), R19.E
unnamed: IC4.6 (-IN), J8.2
unnamed: IC5.5 (+IN), R19.S
unnamed: C8.-, C9.-, IC5.6 (-IN), IC5.7 (OUT)
unnamed: C9.+, J7.3
unnamed: IC4.7 (OUT), J8.1
unnamed: LED_03.C, R20.2
OLEDDC: SV1.6, SV2.10
OLEDRES: SV1.5, SV2.11
OPAMPIN: IC4.3 (+IN), J8.4
OPAMPOUT: IC4.1 (OUT), J1.9, R15.E, R15.S
PIN2: J9.11, TEENSY3.2.2
PIN3: J9.10, TEENSY3.2.3 (3/CAN-TX/PWM)
PIN4: J9.9, TEENSY3.2.4 (4/CAN-RX/PWM)
PIN5: J9.8, TEENSY3.2.5 (5/PWM)
PIN6: J9.7, TEENSY3.2.6 (6/PWM)
POT01: J1.6, R7.3
POT02: J1.7, R8.3
SENSORPORT: J1.8, R9.2, R10.2, R11.2, X8.2
V+: C1.+, C3.+, D3.C, D4.C, EXT_5V1.1, IC2.8 (VCC2), JP1.1, X1.1, X4.1, X5.1
VBAT: TEENSY3.2.VBAT
VMOT: C7.+, DRV8825.VMOT, JP1.2, X3.1
VUSB: TEENSY3.2.VUSB

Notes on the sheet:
POWER
INPUT 7 - 20 Volt
MC 7805 CDTG (1A)
TEENSY 3.2 | LC
dummy stecker guten rausuchen
MOSFET01
LM293
MOSFET02
POTS
STEPPERDRIVER
SENSORPORT
BUTTONS
MAX7219/OLED
OPAMP
BETTEROUT
designed by Felix Fisgus
USERLEDS

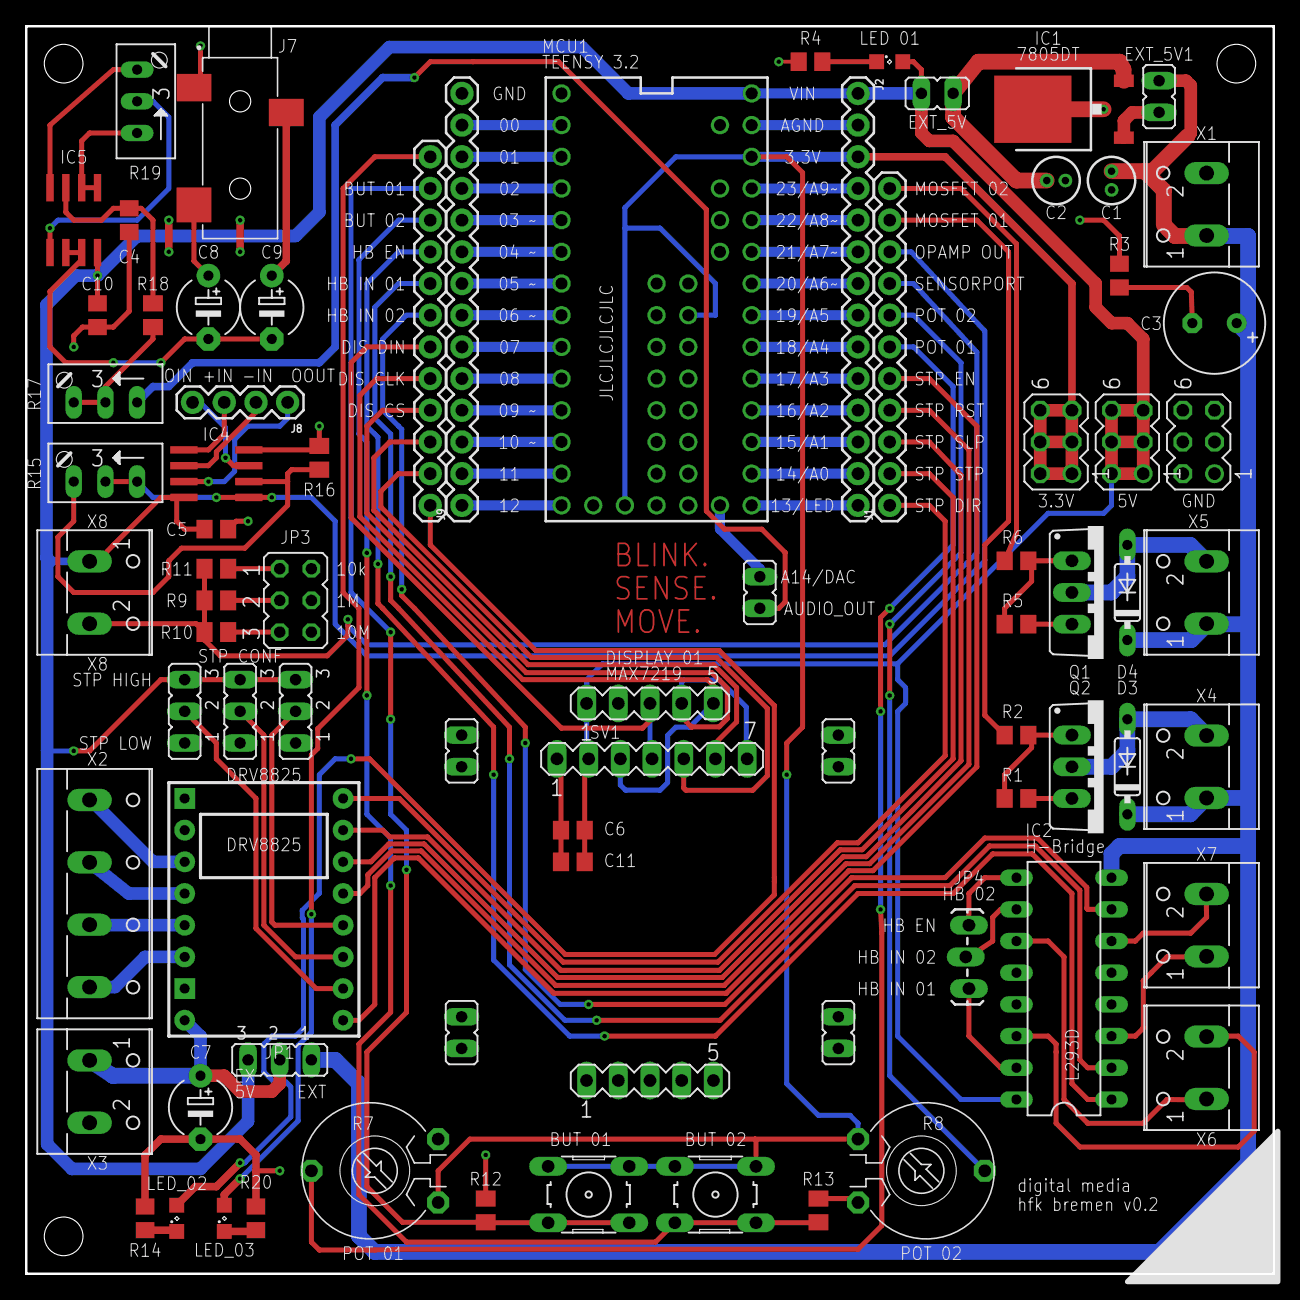
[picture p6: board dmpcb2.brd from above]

Board: 2 copper layers, 100.0 x 100.0 mm, 79 parts (0 on the bottom side), 94 nets.

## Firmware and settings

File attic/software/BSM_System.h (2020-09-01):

#pragma once

//Buttons
#define BUTTON_01 2
#define BUTTON_02 3

//H-Bridge, first half
#define HBRIDGE_ENABLE 4
#define HBRIDGE_IN_01 5
#define HBRIDGE_IN_02 6

//Display, Dotmatrix
#define DISPLAY_DIN 7
#define DISPLAY_CLK 8
#define DISPLAY_CS 9

//Display, OLED, Uncomment the following lines
/*
#define DISPLAY_DC 10
#define DISPLAY_RES 11
*/

//LEDs
#define LED_01 12
#define LED_02 1

//Stepper driver 
#define STEPPER_DIR 13 //Also switches on board LED of Teensy
#define STEPPER_STP 14
#define STEPPER_SLP 15
#define STEPPER_RST 16
#define STEPPER_EN 17

//Potentiometers
#define POTENTIOMETER_01 18
#define POTENTIOMETER_02 19

//Sensorport
#define SENSORPORT 20

//Opamp
#define OPAMP_OUT 21

//Mosfets
#define MOSFET_01 22
#define MOSFET_02 23

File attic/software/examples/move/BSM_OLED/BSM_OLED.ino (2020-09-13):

/**************************************************************************
 This sektch demonstrates the use of OLEDs based on SSD1306 drivers
 with the Blink Sense Move Board.
 To use the OLED connect the corresponding pins for the display (DISPLAY_CLK, DISPLAY_CS, DISPLAY_DC, DISPLAY_DIN and DISPLAY_RES) to their Teensy pins using jumpers.

 It is based on the on the Adafruit OLED example.

 This example is for a 128x64 pixel display using SPI to communicate
 4 or 5 pins are required to interface.

 Original sketch written by Limor Fried/Ladyada for Adafruit Industries,
 with contributions from the open source community.
 BSD license, check license.txt for more information
 All text above, and the splash screen below must be
 included in any redistribution.
 **************************************************************************/

/* include the libraries used in this sketch.*/
#include <SPI.h>
#include <Wire.h>
#include <Adafruit_GFX.h>
#include <Adafruit_SSD1306.h>
#include "BSM_System.h"

/* defines screen width and hight of the display in pixels*/
#define SCREEN_WIDTH 128
#define SCREEN_HEIGHT 64

/* initiates the display with the corresponding pins.*/
Adafruit_SSD1306 display(SCREEN_WIDTH, SCREEN_HEIGHT,
  DISPLAY_DIN, DISPLAY_CLK, DISPLAY_DC, DISPLAY_RES, DISPLAY_CS);


/* Comment out above, uncomment this block to use hardware SPI
#define OLED_DC     6
#define OLED_CS     7
#define OLED_RESET  8
Adafruit_SSD1306 display(SCREEN_WIDTH, SCREEN_HEIGHT,
  &SPI, OLED_DC, OLED_RESET, OLED_CS);
*/

/* Number of snowflakes in the animation example*/
#define NUMFLAKES     10 

#define LOGO_HEIGHT   16
#define LOGO_WIDTH    16
static const unsigned char PROGMEM logo_bmp[] = { B00000000, B11000000,
  B00000001, B11000000,
  B00000001, B11000000,
  B00000011, B11100000,
  B11110011, B11100000,
  B11111110, B11111000,
  B01111110, B11111111,
  B00110011, B10011111,
  B00011111, B11111100,
  B00001101, B01110000,
  B00011011, B10100000,
  B00111111, B11100000,
  B00111111, B11110000,
  B01111100, B11110000,
  B01110000, B01110000,
  B00000000, B00110000 };

void setup() {
  Serial.begin(9600);

  /* SSD1306_SWITCHCAPVCC = generate display voltage from 3.3V internally */
  if(!display.begin(SSD1306_SWITCHCAPVCC)) {
    Serial.println(F("SSD1306 allocation failed"));
    /*Don't proceed, loop forever */
    for(;;); 
  }

  /* Show initial display buffer contents on the screen --
  the library initializes this with an Adafruit splash screen.*/
  display.display();
  delay(2000);

  /* Clear the buffer */
  display.clearDisplay();

  /* Draw a single pixel in white */
  display.drawPixel(10, 10, SSD1306_WHITE);

  /* Show the display buffer on the screen. You MUST call display() after
  drawing commands to make them visible on screen! */
  display.display();
  delay(2000);
  /* display.display() is NOT necessary after every single drawing command,
  unless that's what you want...rather, you can batch up a bunch of
  drawing operations and then update the screen all at once by calling
  display.display(). These examples demonstrate both approaches... */

  testdrawline();      /* Draw many lines*/

  testdrawrect();      /* Draw rectangles (outlines)*/

  testfillrect();      /* Draw rectangles (filled)*/

  testdrawcircle();    /* Draw circles (outlines)*/

  testfillcircle();    /* Draw circles (filled)*/

  testdrawroundrect(); /* Draw rounded rectangles (outlines)*/

  testfillroundrect(); /* Draw rounded rectangles (filled)*/

  testdrawtriangle();  /* Draw triangles (outlines)*/

  testfilltriangle();  /* Draw triangles (filled)*/

  testdrawchar();      /* Draw characters of the default font*/

  testdrawstyles();    /* Draw 'stylized' characters*/

  testscrolltext();    /* Draw scrolling text*/

  testdrawbitmap();    /* Draw a small bitmap image*/

  /* Invert and restore display, pausing in-between*/
  display.invertDisplay(true);
  delay(1000);
  display.invertDisplay(false);
  delay(1000);

  /* Animate bitmaps*/
  testanimate(logo_bmp, LOGO_WIDTH, LOGO_HEIGHT); 
}

void loop() {
}

void testdrawline() {
  int16_t i;

  /* Clear display buffer*/
  display.clearDisplay(); 

  for(i=0; i<display.width(); i+=4) {
    display.drawLine(0, 0, i, display.height()-1, SSD1306_WHITE);
    display.display(); /* Update screen with each newly-drawn line*/
    delay(1);
  }
  for(i=0; i<display.height(); i+=4) {
    display.drawLine(0, 0, display.width()-1, i, SSD1306_WHITE);
    display.display();
    delay(1);
  }
  delay(250);

  display.clearDisplay();

  for(i=0; i<display.width(); i+=4) {
    display.drawLine(0, display.height()-1, i, 0, SSD1306_WHITE);
    display.display();
    delay(1);
  }
  for(i=display.height()-1; i>=0; i-=4) {
    display.drawLine(0, display.height()-1, display.width()-1, i, SSD1306_WHITE);
    display.display();
    delay(1);
  }
  delay(250);

  display.clearDisplay();

  for(i=display.width()-1; i>=0; i-=4) {
    display.drawLine(display.width()-1, display.height()-1, i, 0, SSD1306_WHITE);
    display.display();
    delay(1);
  }
  for(i=display.height()-1; i>=0; i-=4) {
    display.drawLine(display.width()-1, display.height()-1, 0, i, SSD1306_WHITE);
    display.display();
    delay(1);
  }
  delay(250);

  display.clearDisplay();

  for(i=0; i<display.height(); i+=4) {
    display.drawLine(display.width()-1, 0, 0, i, SSD1306_WHITE);
    display.display();
    delay(1);
  }
  for(i=0; i<display.width(); i+=4) {
    display.drawLine(display.width()-1, 0, i, display.height()-1, SSD1306_WHITE);
    display.display();
    delay(1);
  }

  delay(2000); /* Pause for 2 seconds*/
}

void testdrawrect(void) {
  display.clearDisplay();

  for(int16_t i=0; i<display.height()/2; i+=2) {
    display.drawRect(i, i, display.width()-2*i, display.height()-2*i, SSD1306_WHITE);
    display.display(); /* Update screen with each newly-drawn rectangle*/
    delay(1);
  }

  delay(2000);
}

void testfillrect(void) {
  display.clearDisplay();

  for(int16_t i=0; i<display.height()/2; i+=3) {
    /* The INVERSE color is used so rectangles alternate white/black*/
    display.fillRect(i, i, display.width()-i*2, display.height()-i*2, SSD1306_INVERSE);
    display.display(); /* Update screen with each newly-drawn rectangle*/
    delay(1);
  }

  delay(2000);
}

void testdrawcircle(void) {
  display.clearDisplay();

  for(int16_t i=0; i<max(display.width(),display.height())/2; i+=2) {
    display.drawCircle(display.width()/2, display.height()/2, i, SSD1306_WHITE);
    display.display();
    delay(1);
  }

  delay(2000);
}

void testfillcircle(void) {
  display.clearDisplay();

  for(int16_t i=max(display.width(),display.height())/2; i>0; i-=3) {
    /* The INVERSE color is used so circles alternate white/black*/
    display.fillCircle(display.width() / 2, display.height() / 2, i, SSD1306_INVERSE);
    display.display(); /* Update screen with each newly-drawn circle*/
    delay(1);
  }

  delay(2000);
}

void testdrawroundrect(void) {
  display.clearDisplay();

  for(int16_t i=0; i<display.height()/2-2; i+=2) {
    display.drawRoundRect(i, i, display.width()-2*i, display.height()-2*i,
      display.height()/4, SSD1306_WHITE);
    display.display();
    delay(1);
  }

  delay(2000);
}

void testfillroundrect(void) {
  display.clearDisplay();

  for(int16_t i=0; i<display.height()/2-2; i+=2) {
    /* The INVERSE color is used so round-rects alternate white/black*/
    display.fillRoundRect(i, i, display.width()-2*i, display.height()-2*i,
      display.height()/4, SSD1306_INVERSE);
    display.display();
    delay(1);
  }

  delay(2000);
}

void testdrawtriangle(void) {
  display.clearDisplay();

  for(int16_t i=0; i<max(display.width(),display.height())/2; i+=5) {
    display.drawTriangle(
      display.width()/2  , display.height()/2-i,
      display.width()/2-i, display.height()/2+i,
      display.width()/2+i, display.height()/2+i, SSD1306_WHITE);
    display.display();
    delay(1);
  }

  delay(2000);
}

void testfilltriangle(void) {
  display.clearDisplay();

  for(int16_t i=max(display.width(),display.height())/2; i>0; i-=5) {
    /* The INVERSE color is used so triangles alternate white/black*/
    display.fillTriangle(
      display.width()/2  , display.height()/2-i,
      display.width()/2-i, display.height()/2+i,
      display.width()/2+i, display.height()/2+i, SSD1306_INVERSE);
    display.display();
    delay(1);
  }

  delay(2000);
}

void testdrawchar(void) {
  display.clearDisplay();

  display.setTextSize(1);      /* Normal 1:1 pixel scale*/
  display.setTextColor(SSD1306_WHITE); /* Draw white text*/
  display.setCursor(0, 0);     /* Start at top-left corner*/
  display.cp437(true);         /* Use full 256 char 'Code Page 437' font*/

  /* Not all the characters will fit on the display. This is normal.
  Library will draw what it can and the rest will be clipped.*/
  for(int16_t i=0; i<256; i++) {
    if(i == '\n') display.write(' ');
    else          display.write(i);
  }

  display.display();
  delay(2000);
}

void testdrawstyles(void) {
  display.clearDisplay();

  display.setTextSize(1);             /* Normal 1:1 pixel scale*/
  display.setTextColor(SSD1306_WHITE);        /* Draw white text*/
  display.setCursor(0,0);             /* Start at top-left corner*/
  display.println(F("Hello, Blink Sense Move"));

  display.setTextColor(SSD1306_BLACK, SSD1306_WHITE); /* Draw 'inverse' text*/
  display.println(3.141592);

  display.setTextSize(2);             /* Draw 2X-scale text*/
  display.setTextColor(SSD1306_WHITE);
  display.print(F("0x")); display.println(0xDEADBEEF, HEX);

  display.display();
  delay(2000);
}

void testscrolltext(void) {
  display.clearDisplay();

  display.setTextSize(2); /* Draw 2X-scale text*/
  display.setTextColor(SSD1306_WHITE);
  display.setCursor(10, 0);
  display.println(F("scroll"));
  display.display();      /*/ Show initial text*/
  delay(100);

  /* Scroll in various directions, pausing in-between:*/
  display.startscrollright(0x00, 0x0F);
  delay(2000);
  display.stopscroll();
  delay(1000);
  display.startscrollleft(0x00, 0x0F);
  delay(2000);
  display.stopscroll();
  delay(1000);
  display.startscrolldiagright(0x00, 0x07);
  delay(2000);
  display.startscrolldiagleft(0x00, 0x07);
  delay(2000);
  display.stopscroll();
  delay(1000);
}

void testdrawbitmap(void) {
  display.clearDisplay();

  display.drawBitmap(
    (display.width()  - LOGO_WIDTH ) / 2,
    (display.height() - LOGO_HEIGHT) / 2,
    logo_bmp, LOGO_WIDTH, LOGO_HEIGHT, 1);
  display.display();
  delay(1000);
}

#define XPOS   0 /* Indexes into the 'icons' array in function below*/
#define YPOS   1
#define DELTAY 2

void testanimate(const uint8_t *bitmap, uint8_t w, uint8_t h) {
  int8_t f, icons[NUMFLAKES][3];

  /* Initialize 'snowflake' positions*/
  for(f=0; f< NUMFLAKES; f++) {
    icons[f][XPOS]   = random(1 - LOGO_WIDTH, display.width());
    icons[f][YPOS]   = -LOGO_HEIGHT;
    icons[f][DELTAY] = random(1, 6);
    Serial.print(F("x: "));
    Serial.print(icons[f][XPOS], DEC);
    Serial.print(F(" y: "));
    Serial.print(icons[f][YPOS], DEC);
    Serial.print(F(" dy: "));
    Serial.println(icons[f][DELTAY], DEC);
  }

  for(;;) { /* Loop forever...*/
    display.clearDisplay(); /* Clear the display buffer*/

    /* Draw each snowflake:*/
    for(f=0; f< NUMFLAKES; f++) {
      display.drawBitmap(icons[f][XPOS], icons[f][YPOS], bitmap, w, h, SSD1306_WHITE);
    }

    display.display(); /* Show the display buffer on the screen*/
    delay(200);        /* Pause for 1/10 second*/

    /* Then update coordinates of each flake...*/
    for(f=0; f< NUMFLAKES; f++) {
      icons[f][YPOS] += icons[f][DELTAY];
      /* If snowflake is off the bottom of the screen...*/
      if (icons[f][YPOS] >= display.height()) {
        /* Reinitialize to a random position, just off the top*/
        icons[f][XPOS]   = random(1 - LOGO_WIDTH, display.width());
        icons[f][YPOS]   = -LOGO_HEIGHT;
        icons[f][DELTAY] = random(1, 6);
      }
    }
  }
}

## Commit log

2018-12-12 added MCUs, distinguished between MCUs + boards
2018-12-14 teens header
    [dmpcb.brd, dmpcb.sch]
2018-12-14 provisorische power suppy / spannungsregler
    [dmpcb.brd, dmpcb.sch]
2019-01-04 added mosfet into schematic, wasn´t able to find teensy 3.1 lib, please add to repo
2019-01-05 added lm293 to schematic
    [dmpcb.sch]
2019-01-11 added encoder and pots to idealsist
2019-01-17 added Filtercap, powerled, doubled up the mosfet, also added possiblitiy to jump protectiondiode for mosfets
    [dmpcb.sch]
2019-01-17 added stepperdriver and pots, lm293 still needs some corrections
    [dmpcb.sch]
2019-01-18 cleanup, nothing else
    [dmpcb.sch]
2019-02-18 added Todo to file, buttons, sensorport with variable resistors (had the idea of maybe enabling one of the potis to be jumpered in as a variable resistor?) and 12v to lm293
    [dmpcb.sch]
2019-02-18 changed portlayout, added DNC to the pins in the middle of the teensy
    [dmpcb.sch]
2019-02-22 changed some parts around, added max7219 (only needed if we chose discrete implementation, not the readymade board -> because more expensive), changed the pins around on the teensy. The stepperdriver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
    [dmpcb.sch]
2019-02-22 deleted and removed faulty .brd file
    [dmpcb.brd]
2019-02-22 added fresh .brd file
    [dmpcb.brd]
2019-02-22 Holy hell, I have no idea what I am doing. This is so different from kicad. brb, gone to watch tutorials....
    [dmpcb.brd]
2019-02-26 don´t know what changed. well...
    [dmpcb.brd]
2019-03-19 found footprint for drv8825 carrier board, included it into schematic
    [dmpcb.brd, dmpcb.sch]
2019-06-01 added other teensy lib, has better pin spacing, also added breakout jumpers for all pins (-RX and TX)
    [dmpcb.brd, dmpcb.sch]
2019-06-02 fixed drv8825, also added lm358
    [dmpcb.brd, dmpcb.sch]
2019-06-02 need to add custom component for dotmatrix display
    [dmpcb.brd, dmpcb.sch]
2019-06-03 added jumper around 7805, if 5v load is bigger than 1Amp
    [dmpcb.brd, dmpcb.sch]
2019-06-05 added felix' better audio output (thank you felix). still need to find use for one half opamp. Ideas?
    [dmpcb.brd, dmpcb.sch]
2019-06-05 added missing decoupling cap
    [dmpcb.brd, dmpcb.sch]
2019-06-06 corrected sensorport and changed the second half of the lm358 to a freely user-configurable setup
    [dmpcb.brd, dmpcb.sch]
2019-08-16 routing done
    [dmpcb2.brd, dmpcb2.sch]
2019-08-16 started to add part references and values, also started adding pin names and similar. tried adding nice graphics as bmp but failed horribly...
    [dmpcb2.brd, dmpcb2.sch]
2019-08-20 added component names, deleted component values. still need to add names to AKLs. Maybe drawing zones on the board would be good?
    [dmpcb2.brd, dmpcb2.sch]
2019-08-20 added names fand outs for AKLS
    [dmpcb2.brd]
2019-08-20 fixed some wire stubs
    [dmpcb2.brd]
2019-08-20 fixed mirrored AKLs
    [dmpcb2.brd]
2020-05-28 ver 2
    [dmpcb2.brd]
2020-06-10 issues added and fixed
    [dmpcb2.brd, dmpcb2.sch]
2020-06-10 added possibilty to jump out the lm7805
    [dmpcb2.brd, dmpcb2.sch]
2020-06-10 changed powerconnector
    [dmpcb2.brd]
2020-06-25 moved bypass caps
    [dmpcb2.brd, dmpcb2.sch]
2020-06-29 added support for second display, but only is possible at the time
    [dmpcb2.brd, dmpcb2.sch]
2020-06-29 added second jack for midi, not too sure if position is good. thinking about putting pads on the bottom of the board and making the jack optional?
    [dmpcb2.brd, dmpcb2.sch]
2020-07-02 moved second display a bit upwards
    [dmpcb2.brd]
2020-07-13 removed second 3.5mm jack, drc comes back clean
    [dmpcb2.brd, dmpcb2.sch]
2020-07-14 changed naming (v0.2 instead of v.02), some other small fixes
    [dmpcb2.brd]
2020-07-15 screws fit
    [dmpcb2.brd, dmpcb2.sch]
2020-07-18 added user leds and labeling for opamp
    [dmpcb2.brd, dmpcb2.sch]
2020-07-18 some final cleanup work, orderd first v0.2 pcbs
    [dmpcb2.brd]
2020-08-05 added BOM
    [dmpcb.csv]
2020-08-05 added BOM for v2
    [dmpcb.csv, dmpcb2.csv]
2020-08-07 moved some files
    [dmpcb.brd, dmpcb.sch]
2020-08-07 renamed v02 bom and added v02 schematic as pdf
    [dmpcb2_bom.csv]
2020-09-04 added sense example/Sensorport, added discription into blink example
2020-09-04 added button sketch
2020-09-06 added examples for sound and dc motor
2020-09-29 mosfet example...

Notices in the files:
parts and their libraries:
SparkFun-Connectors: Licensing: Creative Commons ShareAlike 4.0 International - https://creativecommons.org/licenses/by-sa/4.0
